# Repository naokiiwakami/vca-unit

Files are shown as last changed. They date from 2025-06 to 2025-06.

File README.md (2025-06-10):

# vca-unit

WARNING: The module has not been fully tested yet!

This is a compact VCA (Voltage-Controlled Amplifier) unit that operates without any additional
external components. Its small form factor — approximately 22mm × 10.5mm — makes it ideal for
integration as a submodule in larger synthesizer projects. The module features six pins arranged
in two rows with a 2.54mm pitch, spaced seven pitches apart. It is also compatible with standard
breadboards..

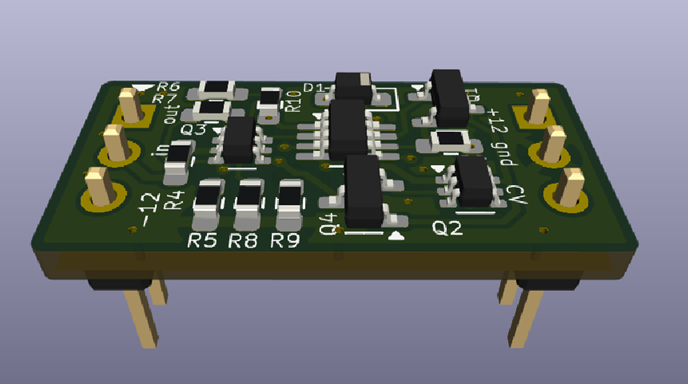
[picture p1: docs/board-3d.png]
board-3d-image


The unit has been tested with a ±12V symmetrical power supply. Basic specifications are as follows:

- **Input signal range:** -8V to +8V (recommended: -5V to +5V)
- **CV range**: 0V to 8V *(unity gain is achieved at approximately 4.6V)*

Below is a simple usage of the module.

vca-unit-usage

This repository includes the KiCad project files, along with the symbol and footprint for the unit.

The schematic is shown below.  Assembly does not require any trimming or calibration.
vca-unit-schematic

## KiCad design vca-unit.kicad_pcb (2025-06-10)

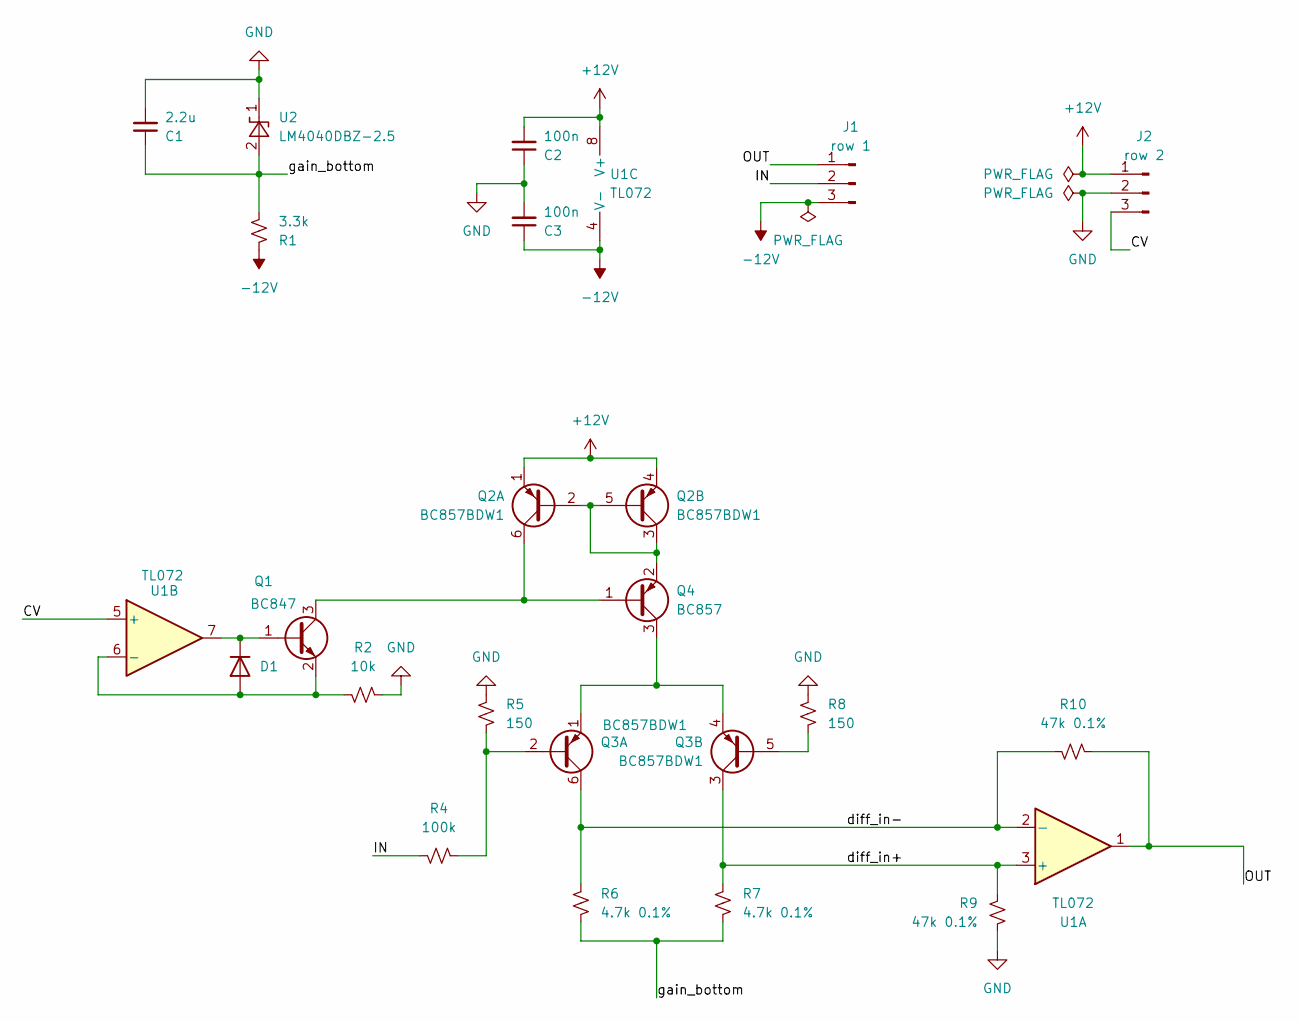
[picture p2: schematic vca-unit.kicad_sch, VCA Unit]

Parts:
C1: 2.2u; C_0603_1608Metric_Pad1.08x0.95mm_HandSolder
C2, C3: 100n; C_0603_1608Metric_Pad1.08x0.95mm_HandSolder
D1: 1N4148; D_SOD-323_HandSoldering
J1: row 1; PinHeader_1x03_P2.54mm_Vertical
J2: row 2; PinHeader_1x03_P2.54mm_Vertical
Q1: BC847; SOT-23
Q2, Q3: BC857BDW1; SOT-363_SC-70-6
Q4: BC857; SOT-23
R1: 3.3k; R_0603_1608Metric_Pad0.98x0.95mm_HandSolder
R2: 10k; R_0603_1608Metric_Pad0.98x0.95mm_HandSolder
R4: 100k; R_0603_1608Metric_Pad0.98x0.95mm_HandSolder
R5, R8: 150; R_0603_1608Metric_Pad0.98x0.95mm_HandSolder
R6, R7: 4.7k 0.1%; R_0603_1608Metric_Pad0.98x0.95mm_HandSolder
R9, R10: 47k 0.1%; R_0603_1608Metric_Pad0.98x0.95mm_HandSolder
U1: TL072; SOT-23-8_Handsoldering
U2: LM4040DBZ-2.5; SOT-23

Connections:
+12V: C2.2, J2.1, Q2.1 (E1), Q2.4 (E2), U1.8 (V+)
-12V: C3.1, J1.3, R1.1, U1.4 (V-)
/CV: J2.3, U1.5 (+)
/IN: J1.2, R4.2
/OUT: J1.1, R10.2, U1.1
/diff_in+: Q3.3 (C2), R7.1, R9.2, U1.3 (+)
/diff_in-: Q3.6 (C1), R6.1, R10.1, U1.2 (-)
/gain_bottom: C1.1, R1.2, R6.2, R7.2, U2.2 (A)
GND: C1.2, C2.1, C3.2, J2.2, R2.1, R5.1, R8.1, R9.1, U2.1 (K)
unnamed: D1.2 (A), Q1.2 (E), R2.2, U1.6 (-)
unnamed: D1.1 (K), Q1.1 (B), U1.7
unnamed: Q1.3 (C), Q2.6 (C1), Q4.1 (B)
unnamed: Q2.2 (B1), Q2.3 (C2), Q2.5 (B2), Q4.2 (E)
unnamed: Q3.2 (B1), R4.1, R5.2
unnamed: Q3.1 (E1), Q3.4 (E2), Q4.3 (C)
unnamed: Q3.5 (B2), R8.2

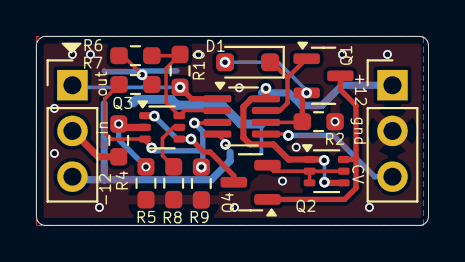
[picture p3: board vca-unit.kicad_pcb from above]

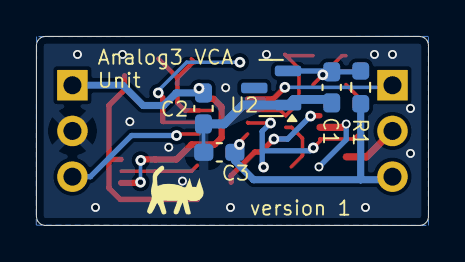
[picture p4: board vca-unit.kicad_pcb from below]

Board: 2 copper layers, 21.8 x 10.5 mm, 21 parts (5 on the bottom side), 16 nets.

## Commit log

2025-06-10 Fix schematic
2025-06-10 Update the schematic in doc again
